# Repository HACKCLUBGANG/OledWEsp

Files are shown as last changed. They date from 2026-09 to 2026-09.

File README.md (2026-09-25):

# KuromiOled
# OledWEsp

OledWEsp stands for An Oled display with Esp32-c3 all put in a compact case to make it good for travelling around with as a keychain
It has a esp32-c3-super-mini which was the smallest devboard i could find for a cheap price. 
It uses a 450mah Battery with a tp4056 charging module
It uses a 1.3 inch oled display which has a cute kuromi animation
I made it to give it to my sister as a gift!
Might add wifi later
Made in Forge - forge.hackclub.com Tier3 Project.


# CASE


{27069CBD-FDC9-4202-85EB-EC40A4797EC0}




# Schematics


# Assembly
after buying all of the components follow these step to assemble your own oled keychain

1st step is 3d printing the parts. Download the print.step file from cad folder in this repository slice it and print it out
2nd step is putting the oled in the 3d part first
Tilt it at this angle and out it in the hole i made 





Then straighten the oled and slide it in the case like this
{54DE5FAB-DECF-4AEF-854F-02B2FB19FE32}


PLACE THE OLED IN THIS WAY SO THAT THE SCREEN IS LIKE THIS

from inside the case add hot glue or tape to make it not move.

Next step is soldering the esp32 board and the female 4 pin connector for the oled to the prototype board board
cut the proto board to the size of 13 x 10 holes
{BF238F17-1847-4C8C-B080-DE1D6C71CB80}

solder them in this way



 

 here u have to connect the oled by looking at the schematics that are shared in this use the wires and heat shrink tubes to protect the wires and conenct them
 

 Next step is to solder the connections of the tp4056 module and esp32
 The BOOST MODULE 3dmodel was not found so i didnt add it to the 3d model but u have to connect it according to the schematics and put it in the case it is small and can fit anywhere 
 make the wires a bit longer because the batery will go between the tp4056 module and the pcbboard


 Next step is to add the battery
 use tape to stick the battery to the board like this 
 and stick the tp4056 module on top of it
{9CC12949-A684-44E9-BA49-98179E08D007}



put the switch in the hole too i couldnt find a 3d model for it then line up the usb ports with the slots in the 3d print and attach the female 4 pin connector with the oled screen. 
Then the inner parts are done

Now for the screws part u have to use a soldering iron to make the brass inserts hot enought to melt the holes i made for the brass inserts 
place the insert like this

Use the soldering iron and push it in the hole 


put this piece in and stick it using glue to cover the hole on the bottom 


AND UR OLED KEYCHAIN IS READY!!!

Do this with all 4 

Then put the back lid on and screw the holes in the inserts till tight so that theres no wiggle wiggle

AND UR OLED KEYCHAIN IS READY!!!


# BOM

| # | Item | Specification / Color | Qty | Price (INR) | Link |
|---:|---|---|---:|---:|---|
| 1 | 1.3" I2C OLED Display | White, 4-Pin | 1 | ₹319.00 | [Robu](https://robu.in/product/1-3-inch-i2c-oled-display-module-4-pin-white/) |
| 2 | ESP32-C3 Development Board | With soldering | 1 | ₹279.00 | [Robu](https://robu.in/product/esp32-c3-development-board-with-soldering/) |
| 3 | Boost Converter | 1.5–4.2V → 5V | 1 | ₹119.00 | [Robu](https://robu.in/product/1-5v-to-5v-boost-voltage-conversion-module/) |
| 4 | TP4056 Charger | 1A Li-Ion Charger + Protection, Micro-USB | 1 | ₹19.00 | [Robu](https://robu.in/product/tp4056-1a-lipo-battery-charging-board-micro-usb-with-current-protection/) |
| 5 | WLY52535 LiPo Battery | 3.7V 450mAh, 1S | 1 | ₹299.00 | [Robu](https://robu.in/product/450mah-pcm-protected-micro-li-po-battery/) |
| 6 | Prototype PCB | 3×7cm, Double-Sided | 1 | ₹69.00 | [Robu](https://robu.in/product/37-cm-universal-pcb-prototype-board-double-sided/) |
| 7 | Long Female Header | 1×40 Pin, 2.54mm | 1 | ₹98.00 | [Robu](https://robu.in/product/1-40-pin-2-54m-straight-long-female-berg-strip-connector-pack-of-5/) |
| 8 | Female Header | 1×40 Pin, 2.54mm | 1 | ₹13.00 | [Robu](https://robu.in/product/2-54mm-1x40-pin-female-single-row-header-strip-pack-of-10/) |
| 9 | Noel Solder Wire | 60/40, 1mm, 50g | 1 | ₹309.00 | [Robu](https://robu.in/product/solder-wire-1-00mm-50gm/) |
| 10 | BAKON Soldering Iron Tip | 900M-T-I | 1 | ₹115.00 | [Robu](https://robu.in/product/bakon-soldering-iron-tip-900m-t-i/) |
| 11 | Multitec Wire Stripper & Cutter | 150B | 1 | ₹60.00 | [Robu](https://robu.in/product/multitec-150b-wire-stripper-and-cutter/) |
| 12 | 24 AWG Wire | Solid Core PVC, Red | 2m | ₹20.00 | [Robu](https://robu.in/product/24-awg-solid-core-insulated-wire-pvc-red/) |
| 13 | 24 AWG Wire | Solid Core PVC, Black | 2m | ₹20.00 | [Robu](https://robu.in/product/24-awg-solid-core-insulated-wire-pvc/) |
| 14 | 2mm Heat-Shrink | Black | 2 | ₹20.00 | [Robu](https://robu.in/product/heat-shrink-sleeve-2mm-black-industrial-grade-woer-hst/) |
| 15 | 2mm Heat-Shrink | Red | 2 | ₹24.00 | [Robu](https://robu.in/product/heat-shrink-sleeve-2mm-red-industrial-grade-woer-hst/) |
| 16 | 3mm Heat-Shrink | Black | 2 | ₹12.00 | [Robu](https://robu.in/product/heat-shrink-sleeve-3mm-black-industrial-grade-woer-hst/) |
| 17 | 3mm Heat-Shrink | Red | 2 | ₹16.00 | [Robu](https://robu.in/product/heat-shrink-sleeve-3mm-red-industrial-grade-woer-hst/) |
| 18 | 4mm SPDT 1P2T Slide Switch | — | 4 | ₹11.40 | [Robu](https://robu.in/product/4mm-spdt-1p2t-slide-switch-pack-of-10/) |
| 19 | Insulating Tape | Yellow | 1 | ₹23.00 | [Robu](https://robu.in/product/insulating-tape-yellow%ef%bc%89/) |
| 20 | Curved Tweezers | ESD-15 | 1 | ₹35.00 | [Robu](https://robu.in/product/curved-tweezers-esd-15/) |
| 21 | M2 × 3mm Brass Threaded Insert | Brass | 10 | ₹18.00 | [OnlyScrews](https://onlyscrews.in/products/m2-x-3mm-brass-threaded-inserts) |
| 22 | Micro USB Cable | 50cm, for TP4056 | 1 | ₹39.00 | [Robu](https://robu.in/product/50-cm-micro-usb-cable/) |
| 23 | USB Type-C Cable | 1m, Fast Charging/Data Transfer | 1 | ₹87.00 | [Robu](https://robu.in/product/type-c-usb-cable/) |
| 24 | 3D-Printed Case | Self-made | 1 | ₹0.00 | — |
| 25 | M2 × 5mm Phillips Screw | SS304 | 10 | ₹20.00 | [OnlyScrews](https://onlyscrews.in/collections/m2-screws) |

**Total: ₹1,925.40**

> Robu minimum order value: ₹10 per item.
ROBU HAS A POLICY OF ATLEAST BUYING 10 RUPEES WORTH OF THE PRODUCT thats why i had to buy extra quantities for some like the heat shrink tubes etc

# CART PICS

ONLY SCREWS


ROBU.IN


{0B7D5FEC-286B-403A-B581-89F57651FF1B}

{460EA0BD-C1D5-4DEF-9230-A2A4932FEC1B}



# CREDITS
CREDITS TO https://www.oledanimationmaker.com/ for convering a mp4 file to oled code for this project.

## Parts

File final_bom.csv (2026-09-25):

# | Item | Specification / Color | Qty | Price (INR) | Price (USD) | Link
1 | 1.3" I2C OLED Display | White | 1 | 319.0 | 3.32 | https://robu.in/product/1-3-inch-i2c-oled-display-module-4-pin-white/
2 | ESP32-C3 Development Board | With soldering | 1 | 279.0 | 2.91 | https://robu.in/product/esp32-c3-development-board-with-soldering/
3 | Boost Converter | 1.5–4.2V → 5V | 1 | 119.0 | 1.24 | https://robu.in/product/1-5v-1-8v-2-5v-3v-3-3v-3-7v-4-2v-to-5v-boost-voltage-conversion-module-with-soldering/
4 | TP4056 Charger | 1A Li-Ion Charger + Protection | 1 | 19.0 | 0.2 | https://robu.in/product/tp4056-1a-lipo-battery-charging-board-micro-usb-with-current-protection/
5 | WLY52535 LiPo Battery | 3.7V 450mAh, 1S | 1 | 299.0 | 3.11 | https://robu.in/product/450mah-pcm-protected-micro-li-po-battery/
6 | Prototype PCB | 3×7cm, Double-Sided | 1 | 69.0 | 0.72 | https://robu.in/product/3-x-7-cm-universal-pcb-prototype-board-double-side-2pcs/
7 | Long Female Header | 1×40 Pin, 2.54mm | 1 | 98.0 | 1.02 | https://robu.in/product/1x40-pin-2-54mm-straight-long-female-strip-connector/
8 | Noel Solder Wire | 60/40, 1mm, 50g | 1 | 309.0 | 3.22 | https://robu.in/product/solder-wire-1-00mm-50gm/
9 | BAKON Soldering Iron Tip | 900M-T-I | 1 | 115.0 | 1.2 | https://robu.in/product/bakon-soldering-iron-tip-900m-t-i/
10 | Multitec Wire Stripper & Cutter | 150B | 1 | 60.0 | 0.62 | https://robu.in/product/multitec-150b-wire-stripper-and-cutter/
11 | 24 AWG Wire | Solid Core PVC, Red | 2m | 20.0 | 0.21 | https://robu.in/product/24-awg-solid-core-insulated-wire-pvc-red/
12 | 24 AWG Wire | Solid Core PVC, Black | 2m | 20.0 | 0.21 | https://robu.in/product/24-awg-solid-core-insulated-wire-pvc/
13 | 24 AWG Wire | Solid Core PVC, White | 2m | 20.0 | 0.21
14 | 2mm Heat-Shrink | Black | 2 | 20.0 | 0.21 | https://robu.in/product/heat-shrink-sleeve-2mm-black-industrial-grade-woer-hst/
15 | 2mm Heat-Shrink | Red | 2 | 24.0 | 0.25 | https://robu.in/product/heat-shrink-sleeve-2mm-red-industrial-grade-woer-hst/
16 | 3mm Heat-Shrink | Black | 2 | 12.0 | 0.12 | https://robu.in/product/heat-shrink-sleeve-3mm-black-industrial-grade-woer-hst/
17 | 3mm Heat-Shrink | Red | 2 | 16.0 | 0.17 | https://robu.in/product/heat-shrink-sleeve-3mm-red-industrial-grade-woer-hst/
18 | 4mm SPDT 1P2T Slide Switch | Slide Switch | 4 | 11.4 | 0.12 | https://robu.in/product/4mm-spdt-1p2t-slide-switch-pack-of-10/
19 | Insulating Tape | Yellow | 1 | 23.0 | 0.24 | https://robu.in/product/insulating-tape-yellow%ef%bc%89/
20 | M2 × 5mm Phillips Screw | SS304 | 10 | 20.0 | 0.21 | https://onlyscrews.in/collections/m2-screws
21 | M2 × 3mm Brass Threaded Insert | Brass | 10 | 18.0 | 0.19 | https://onlyscrews.in/products/m2-x-3mm-brass-threaded-inserts
22 | Curved Tweezers ESD-15 | ESD-15 | 1 | 35.0 | 0.36 | https://robu.in/product/curved-tweezers-esd-15/
23 | 3D-Printed Case | Self-made | 1 | 0.0 | 0.0
 | TOTAL |  |  | 1925.4 | 20.06

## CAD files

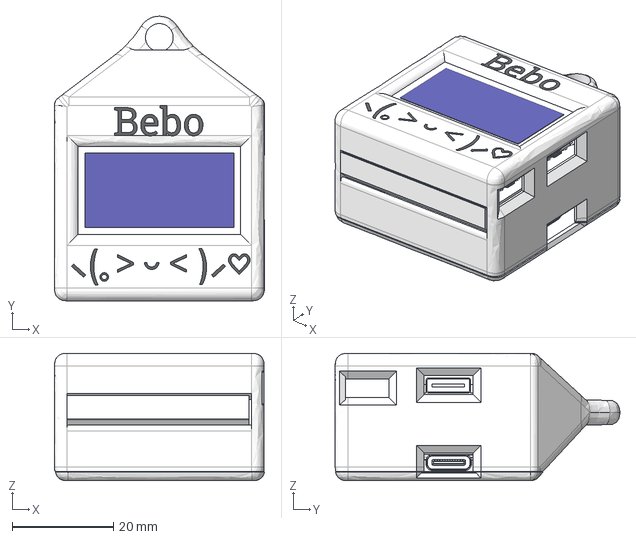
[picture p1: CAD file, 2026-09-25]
cad/FullProjectAssemblyFinal.step
41.5 x 56.2 x 25.2 mm

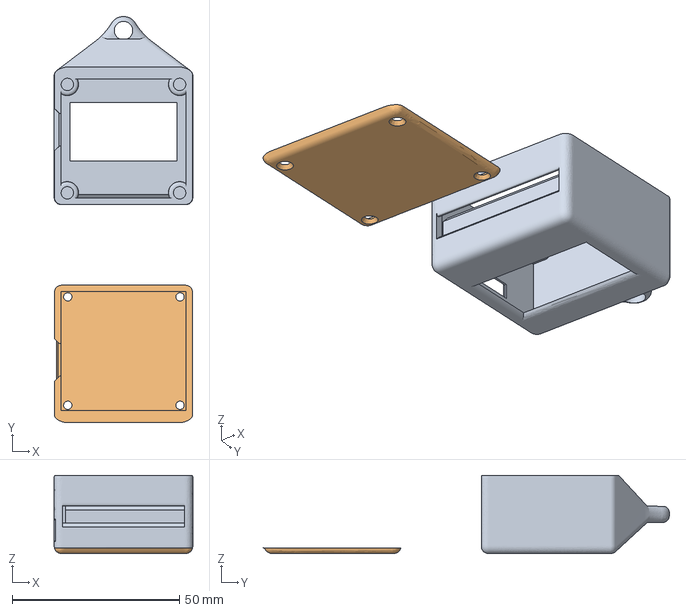
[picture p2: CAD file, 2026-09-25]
cad/Print.3mf
41.4 x 121.2 x 23.3 mm
Prints.step_A
Prints.step_B
